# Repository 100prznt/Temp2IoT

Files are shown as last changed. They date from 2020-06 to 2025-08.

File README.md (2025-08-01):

Temp2IoT wiring

# Temp2IoT
Very basic IoT thermometer with REST API and Web-UI. Implemented according to the "KISS" approach - **K**eep **I**t **S**imple and **S**tupid

## Features
* Temperature measurement at one or two measuring points using DS18B20 sensors
* Shows the measured values on integrated web UI
* REST API for integration with master systems (e.g. ioBroker)
* Configuration also via a web UI

## Hardware

### BOM

| Description | Qty. | Price | ASIN (partner-link from amazon.de) |
|---|---|---:|---|
| WeMos D1 mini | 1 | EUR 6,49  | [B01N9RXGHY](https://amzn.to/3clRAiP) |
| DS18B20 waterproof | 1 or 2 | EUR 3,50  | [B01MZG48OE](https://amzn.to/2NQUkvc) |
| Resistor 2K2 (0,6 W) | 1 | EUR 0,99  | [B007R3QXUE](https://amzn.to/3ja1jww) |
|----------------------|--------|-----------|---------------------------------------|
| Total | | EUR 10,98 | |

*quoted prices from 2022/09/08*

Also a USB-micro cable and a USB power supply is required

### Wiring

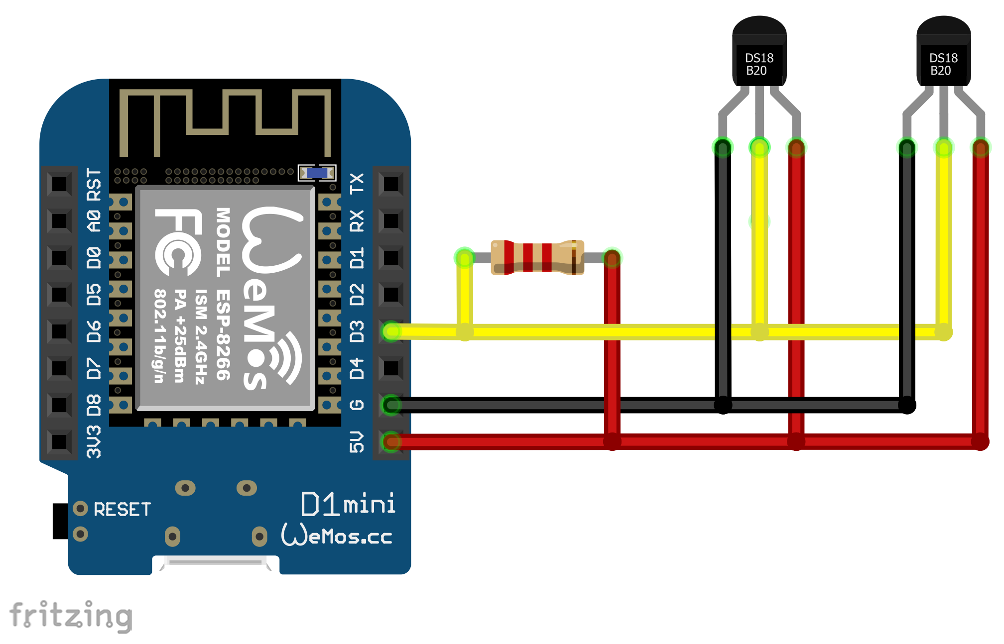
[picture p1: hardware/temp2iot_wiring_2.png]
Temp2IoT wiring


### Power Supply
:warning: Caution Danger to life :warning:

If the thermometer is used to measure water temperatures, it is essential to use an appropriately classified power supply unit. It is important that the power supply is designed as a safety transformer.

A simple USB power supply that meets these requirements can be found here:
* [5V USB-Netzteil mit Sicherheitstransformator | 07-314.0](https://shop.stegertrafo.de/5v-usb-netzteil-mit-sicherheitstransformator-07-314-0.html)

Temp2IoT wiring
Symbol of a short-circuit proof, closed safety transformer 

### Photos

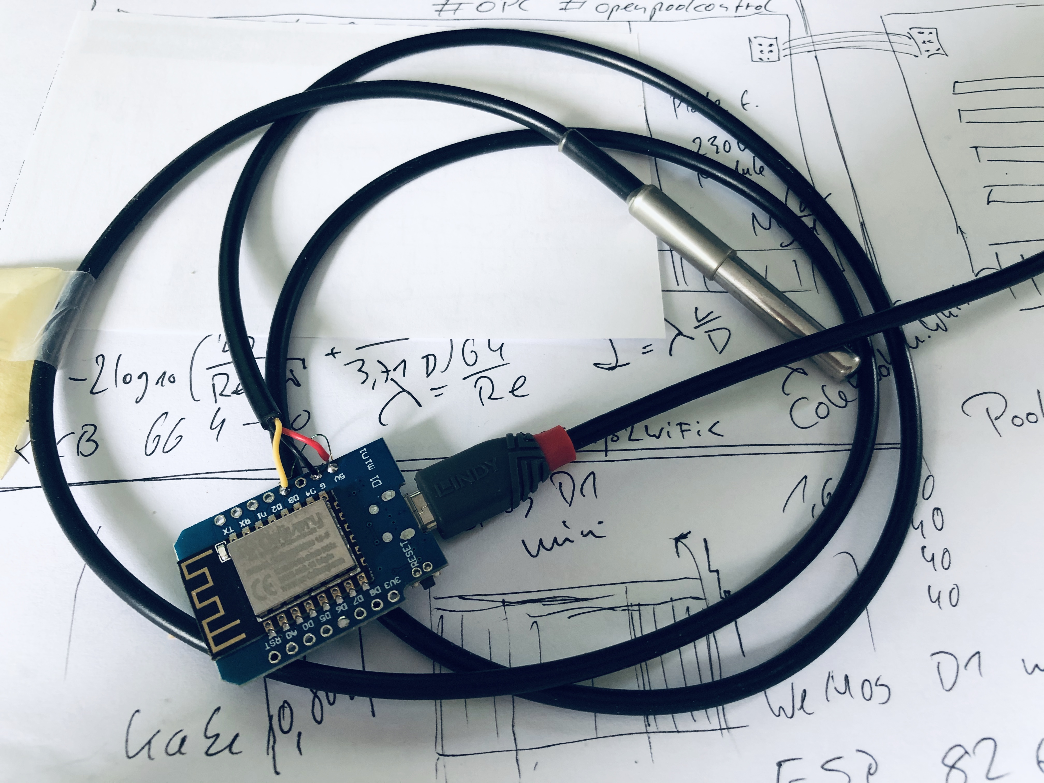
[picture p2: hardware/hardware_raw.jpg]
Temp2IoT minimal build up

Minimal build up with SMD resistor on the back and only one connected DS18B20. 

## Setup

You have two options to upload the software to the WeMos D1 mini.

### ESP8266 Flasher (Windows)

You can download the compiled Flasher Tool from the GitHub Repository
* [nodemcu/nodemcu-flasher](https://github.com/nodemcu/nodemcu-flasher)

1. Clone or download the repository
2. Start the ESP8266Flasher.exe
3. Select the pre-compiled Temp2IoT binary on the config-tab, find at: `src\Temp2IoT\Temp2IoT.ino.d1_mini.bin` (https://github.com/100prznt/Temp2IoT/blob/master/src/Temp2IoT/Temp2IoT.ino.d1_mini.bin)
4. Switch back to the operation-tab and select the right COM-port
5. Press the Flash-Button

## REST API
* URL: `http://<Temp2IoT IP>/api`
* Method: `GET`

```
{
  "systemname": "My Temp2IoT instance",
  "secure_counter": 50,
  "firmware": "2.2.04-b",
  "sensors": [
    {
      "name": "water",
      "value": 23.625,
      "mean-1": {
        "count": 5,
        "value": 23.6,
        "period": 3600
      },
      "mean-24": {
        "count": 5,
        "value": 23.6,
        "period": 86400
      },
      "unit": "Celsius",
      "time": "Fri Jul  9 13:12:36 2021"
    },
    {
      "name": "ambient",
      "value": 23.9375,
      "unit": "Celsius",
      "time": "Fri Jul  9 13:12:37 2021"
    }
  ]
}
```

## Web UI
* URL: `http://<Temp2IoT IP>/`
  <br>
  <br>
  <br>
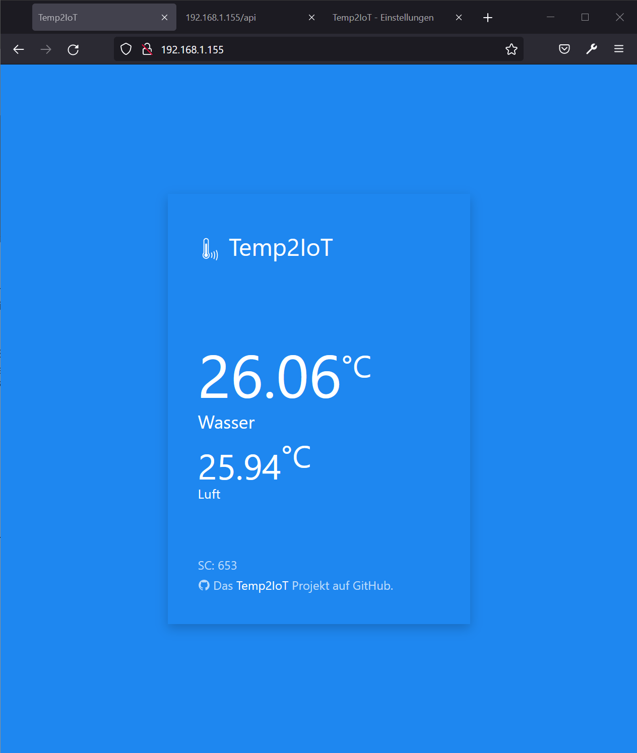
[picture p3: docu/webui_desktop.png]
Web UI on a desktop browser

Web UI on a desktop browser
  <br>
  <br>
  <br>
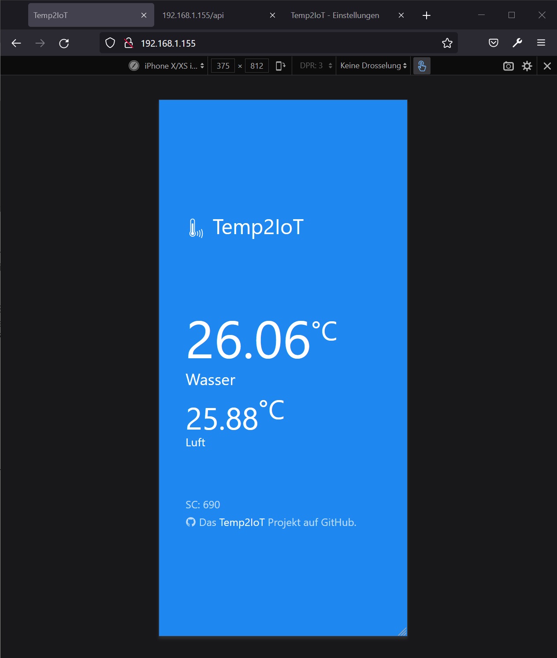
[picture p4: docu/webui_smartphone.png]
Web UI on a smartphone browser

Web UI on a smartphone browser

## System Setup
* URL: `http://<Temp2IoT IP>/setup/`
  <br>
  <br>
  <br>
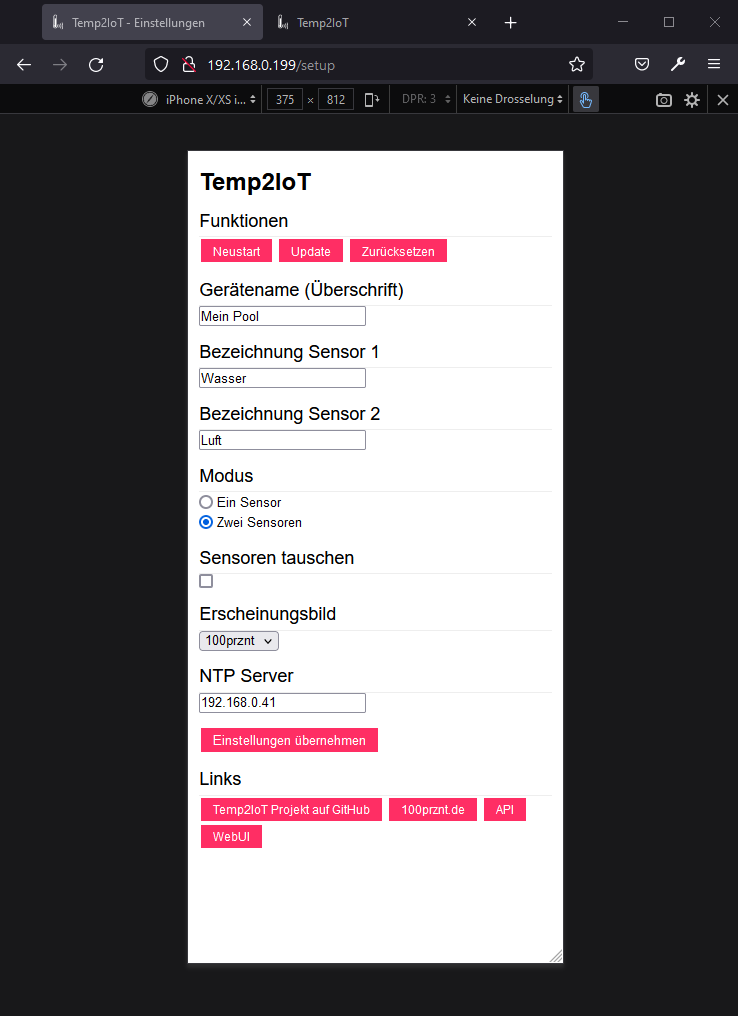
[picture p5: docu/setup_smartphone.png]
Web setup page on a smartphone browser

Setup page on a smartphone browser

## Color Scheme
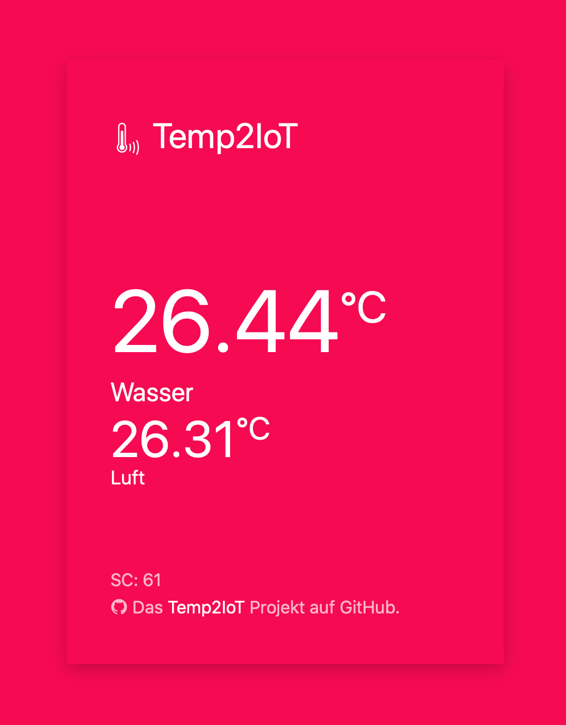
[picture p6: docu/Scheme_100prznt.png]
Temp2IoT Color Scheme 100prznt
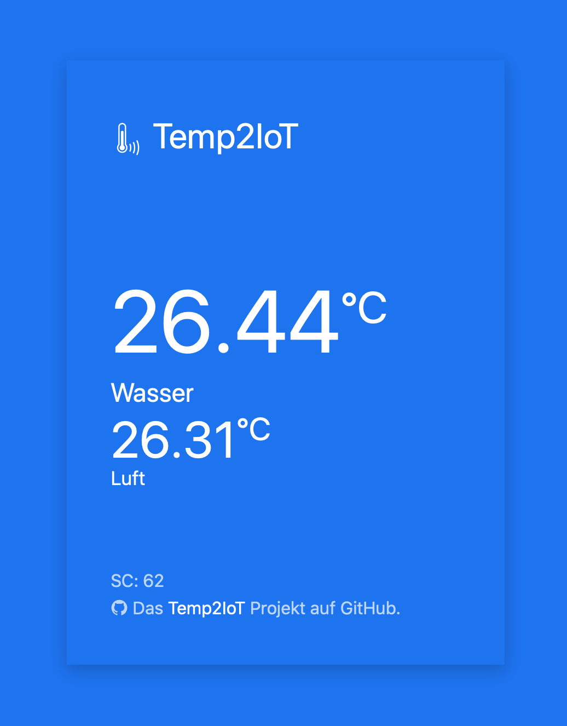
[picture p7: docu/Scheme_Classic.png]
Temp2IoT Color Scheme CLASSIC
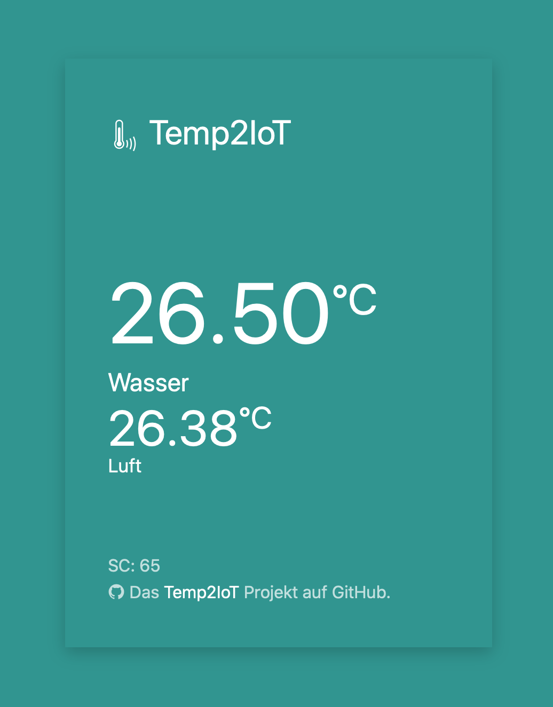
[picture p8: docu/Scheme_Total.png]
Temp2IoT Color Scheme TOTAL
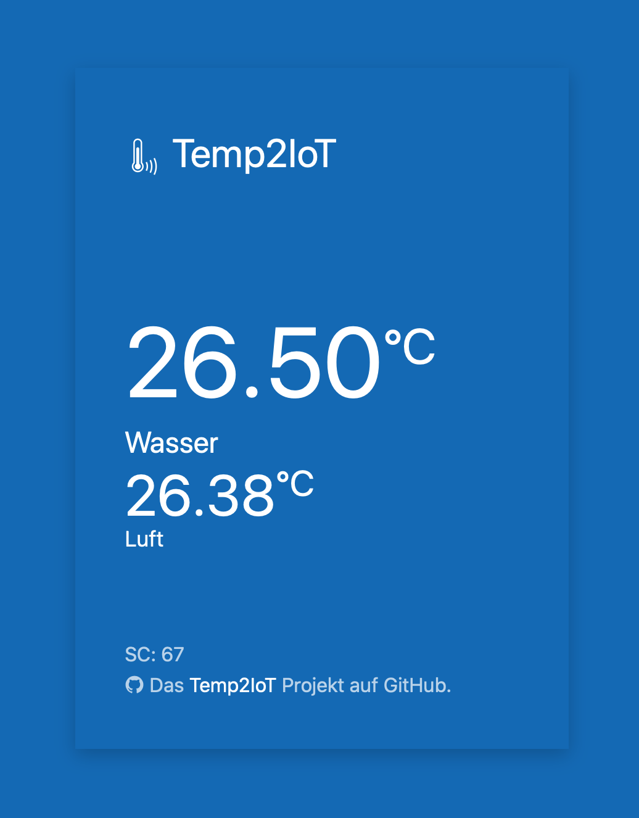
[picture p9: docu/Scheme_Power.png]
Temp2IoT Color Scheme POWER
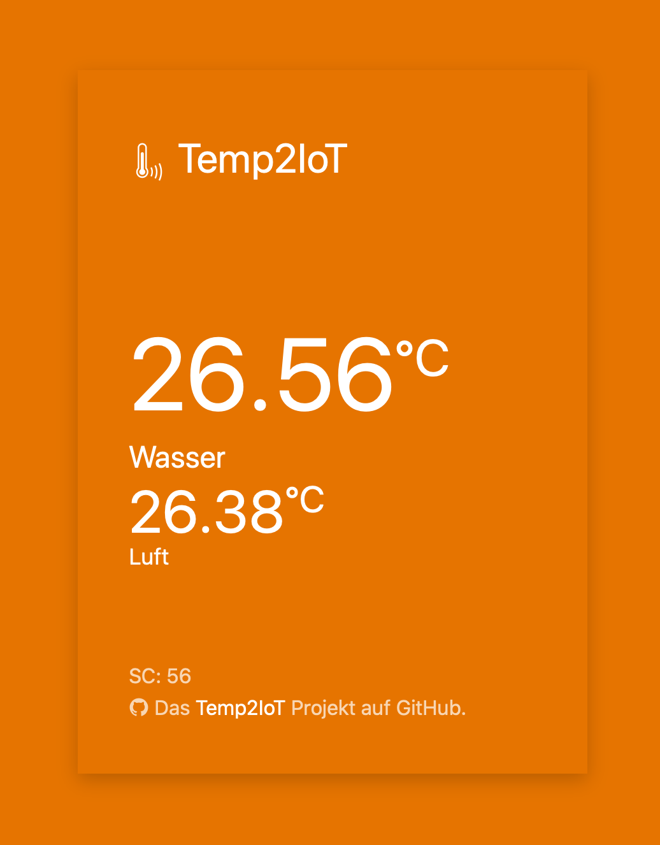
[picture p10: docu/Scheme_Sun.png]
Temp2IoT Color Scheme SUN
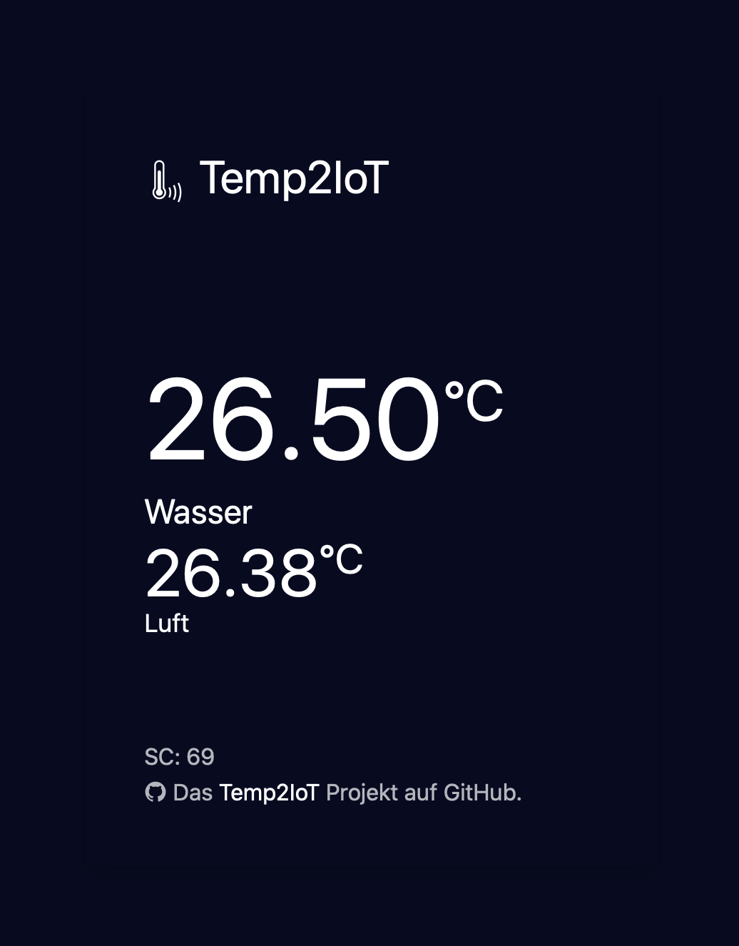
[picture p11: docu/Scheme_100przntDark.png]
Temp2IoT Color Scheme DARK
          

### Colors

| # | scheme | primary color | badge |
|:--|:---|:---|---|
| 1 | 100prznt | `#ff2e64` |  |
| 2 | Classic  | `#1e87f0` |  |
| 3 | Total | `#30a4a1` |  |
| 4 | Power | `#325c84` |  |
| 5 | Sun | `#f08a00` |  |
| 6 | Dark | `#060d2a` |  |

## Debug Output

Feel free to take a look at the serial monitor (115200 baud).

```
21:54:57.656 ->
21:54:57.656 ->        _____               ___ ___    _____       
21:54:57.656 ->       |_   _|__ _ __  _ __|_  )_ _|__|_   _|      
21:54:57.702 ->         | |/ -_) '  \| '_ \/ / | |/ _ \| |        
21:54:57.702 ->         |_|\___|_|_|_| .__/___|___\___/|_|        
21:54:57.702 ->                      |_|                          
21:54:57.702 -> 
21:54:57.702 -> **************************************************
21:54:57.702 ->        a 100prznt.de project by E. Ruemmler       
21:54:57.702 ->                       v2.2.04-b
21:54:57.702 -> 
```

## Enclosure
In the folder [hardware/enclosure](hardware/enclosure) you will find 2 STL files of a suitable enclosure. If the cover is printed upside-down, you can print the first two layers in a different color to make the Temp2IoT icon stand out better.

### Photos

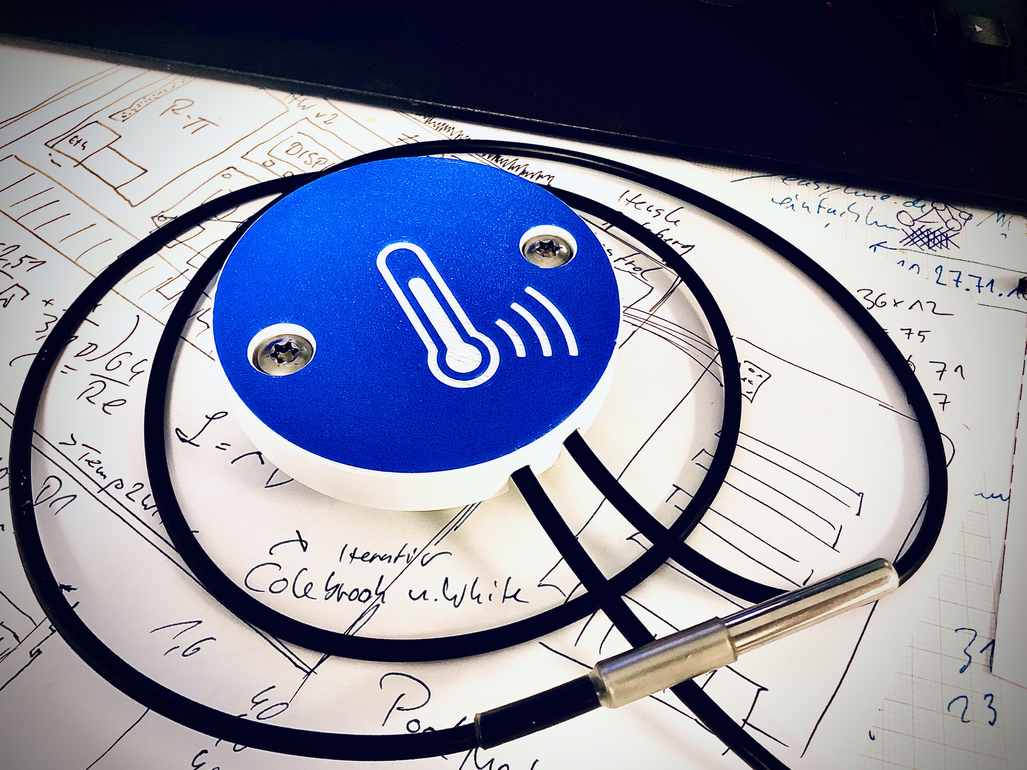
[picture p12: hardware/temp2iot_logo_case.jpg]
3d-printed enclousure with Temp2IoT icon

3d-printed enclousure with Temp2IoT icon
  <br>
  <br>
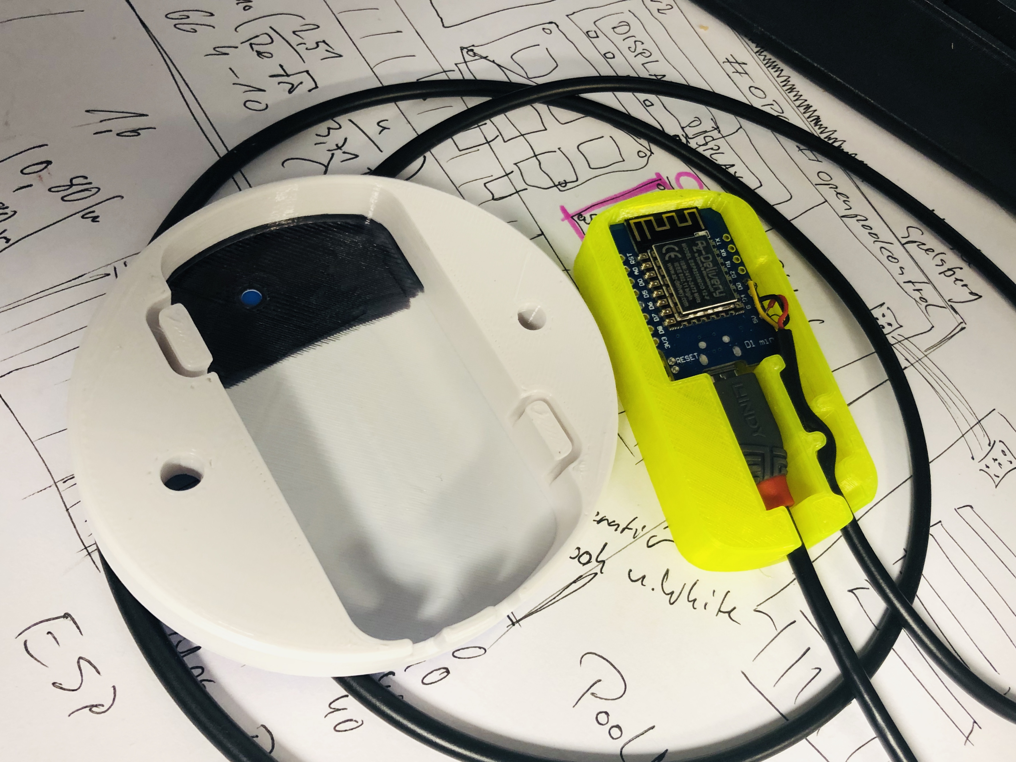
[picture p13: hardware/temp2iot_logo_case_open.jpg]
3d-printed enclousure open

Blackened inside so that the LED produces a focused light spot

## Community
Found this project on the german [Poolpowershop-Forum](https://www.poolpowershop-forum.de/).
* [WiFi Thermometer für 10 Euro selbst gebaut (Web UI, REST API)](https://www.poolpowershop-forum.de/forum/thread/1103493-wifi-thermometer-f%C3%BCr-10-euro-selbst-gebaut-web-ui-rest-api/)

## Credits
This app is made possible by contributions from:
* [Elias Rümmler](http://www.100prznt.de) ([@rmmlr](https://github.com/rmmlr)) - core contributor

### Open Source Project Credits

* [Follower Counter](https://github.com/jegade/followercounter) - The architeture of Temp2IoT based on a awesome code from [@jegade](https://github.com/jegade) used for his followercounter project.
* Used Arduino libraries are described in the code.

## License
The Temp2IoT project is licensed under [MIT](http://www.opensource.org/licenses/mit-license.php "Read more about the MIT license form"). Refer to [LICENSE.txt](https://github.com/100prznt/Temp2IoT/blob/master/LICENSE.txt) for more information.

## Contributions
Contributions are welcome. Fork this repository and send a pull request if you have something useful to add.

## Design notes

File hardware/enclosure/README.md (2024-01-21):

# Temp2IoT Enclosure

The enclosure is optimized for the use of a LINDY *Anthra Line Anthrazit* USB cable.

Partner-link from amazon.de
* [LINDY 36734 3m USB 2.0 Typ A an Micro-B Kabel](https://amzn.to/2YbEmhI)

## STLs

You can find the STL files for the case on Printables.com
* [WeMos D1 mini Enclosure](https://www.printables.com/de/model/44083-wemos-d1-mini-enclosure)

## Assembly

If the cover is printed in a bright color, it can be blackened from the inside to prevent the LED from causing unpleasant stray light.

Printed enclosure parts

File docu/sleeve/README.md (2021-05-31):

Temp2IoT wiring

# Temp2IoT
Very basic IoT thermometer with REST API and Web-UI. Implemented according to the "KISS" approach - **K**eep **I**t **S**imple and **S**tupid

* Go to Project [README.md](https://github.com/100prznt/Temp2IoT)

## Tauchhülse
Möchte man die Wassertemperatur im geschlossenen Kreislauf erfassen bietet sich der Einsatz einer Tauchhülse an. Eine solche Tauchhülse kann zum Beispiel in ein T-Stück mit reduzierten Abgang eingeschraubt werden.

Im Vergleich zu einen außenliegenden Anlegefühler erreicht man mit der Tauchhülse eine wesentlich bessere Dynamik. Die dünnwandige Edelstahl-Hülse leitet wäre einfach besser als ein dickwandiges PVC Rohr.

## BOM

| Description | Qty. | Price | ASIN (partner-link from amazon.de) |
|:---|:-----|---:|:---|
| Tauchhülse 1/2" 50 mm | 1 | EUR 10,99 | [ B07DXFWV6B](https://amzn.to/3eissJy) |

*quoted prices from 2021/04/19*

## Photos

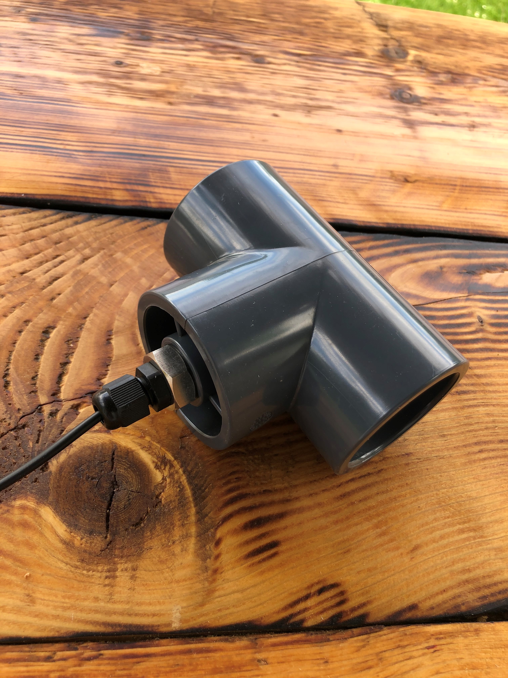
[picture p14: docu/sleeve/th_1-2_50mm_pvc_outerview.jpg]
Im T-Stück eingesetzte Tauchhülse mit 1/2" Gewinde

Im T-Stück eingesetzte Tauchhülse mit 1/2" Gewinde
  <br>
  <br>
  <br>
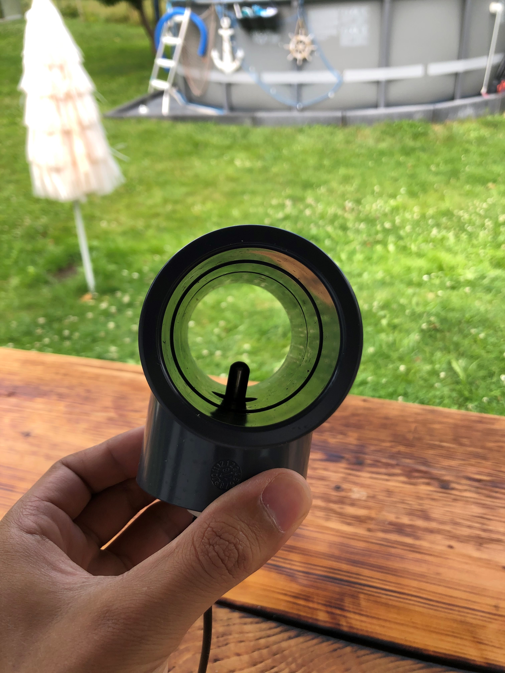
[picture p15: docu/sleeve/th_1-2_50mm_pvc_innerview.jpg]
Mit 50 mm Länge ragt die Hülse minimal in den Hautstrom

Mit 50 mm Länge ragt die Hülse minimal in den Hautstrom. Tieferes Eintauchen erhöht das Risiko das sich Haare festsetzen.

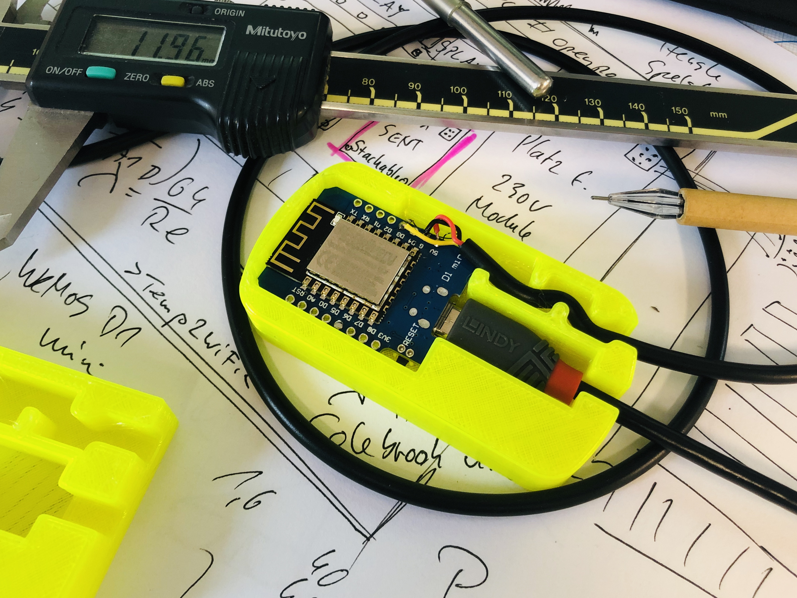
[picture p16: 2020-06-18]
hardware/first_case.jpg

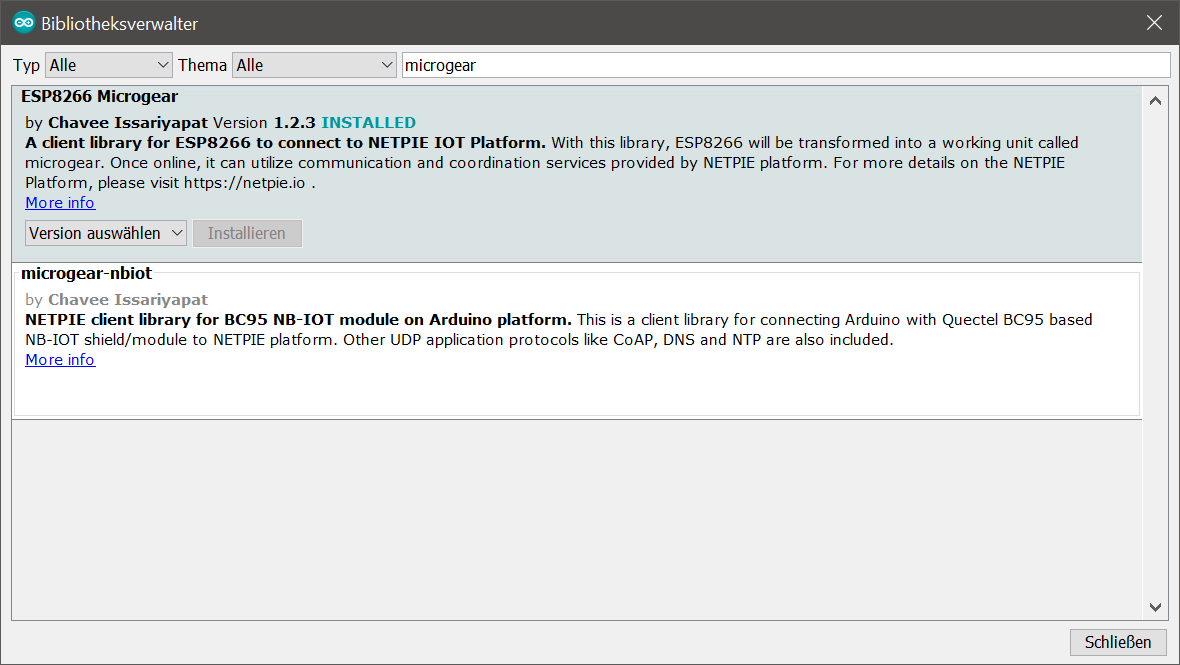
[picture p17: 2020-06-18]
docu/ide_microgear_lib.png

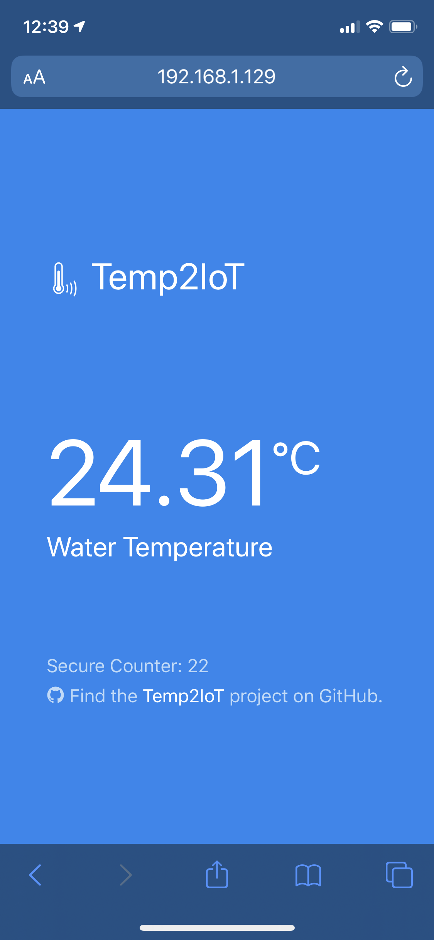
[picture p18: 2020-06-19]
docu/webui_smartphone_real.png

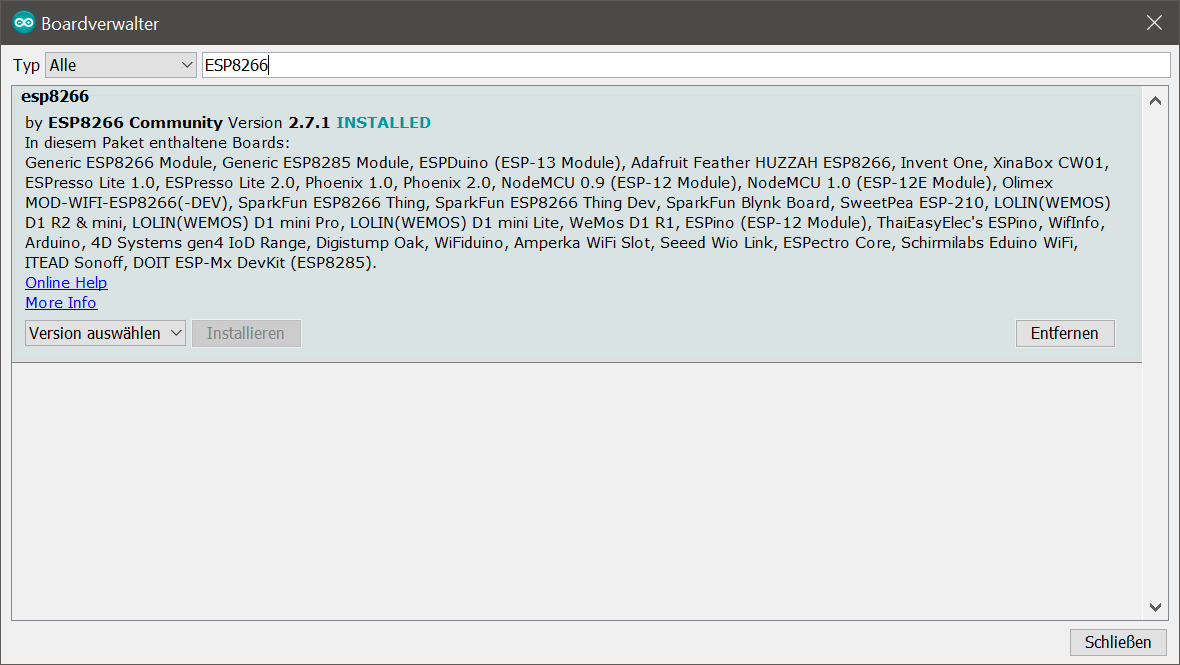
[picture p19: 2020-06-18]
docu/ide_boards.png

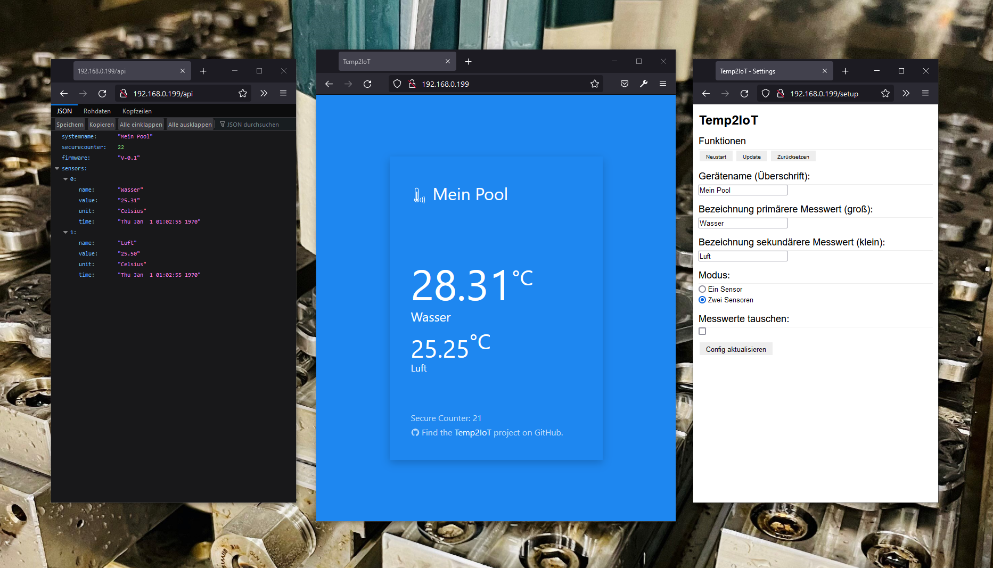
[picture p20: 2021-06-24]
docu/dev_view_v2.png

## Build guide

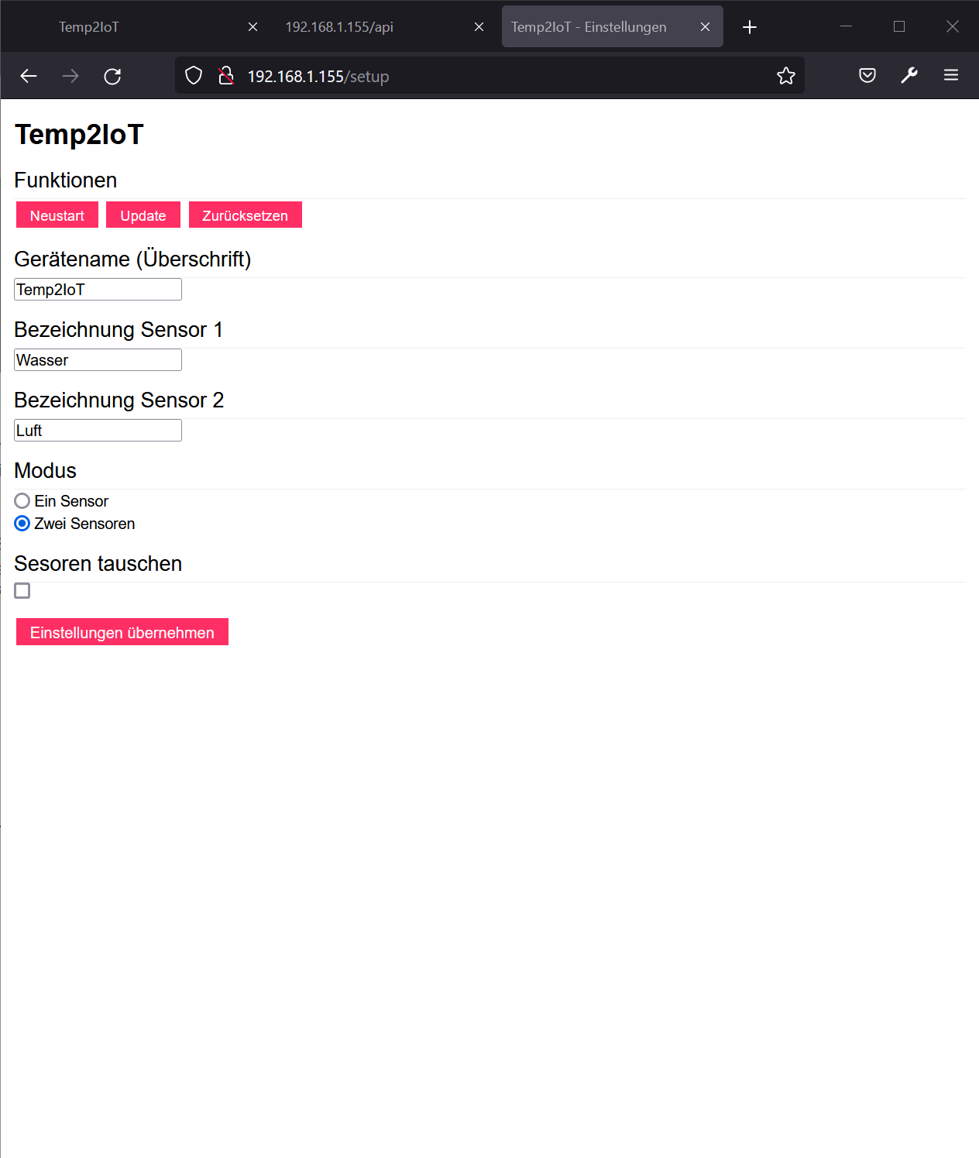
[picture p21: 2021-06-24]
docu/setup_desktop.png

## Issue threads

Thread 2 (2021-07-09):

1-Wire reading failure

100prznt, 2021-07-09:
Check the temperature values for plausibility. Detect and mark faulty values -> return NaN.

100prznt, 2021-07-15:
Implemented in 5e270a9

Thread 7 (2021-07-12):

Unhandled Exception and HttpUpdate fails

100prznt, 2021-07-12:
ESP restart after unhandled exception (mem alloc) and after try to start HttpUpdate.

WiFiManager also don't work... 👎🏻

100prznt, 2021-07-12:
Problem eingegrenzt. Wird durch cppQueue ausgelöst.

Closed 2021-07-14.

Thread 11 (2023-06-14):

4 Sensors

uncle03, 2023-06-14:
Hi,

we have the choice between 1 and 2 sensors. ist it also possible to get 4 sensors ?

So I see: Heatpump in/Heatpump out, bottom pool Temperature and air temperature.

100prznt, 2023-06-14:
The structures for storing and processing sensor data are currently fixed for two sensors. If more sensors should be processed, it's better to change the software architecture so that the processing takes place in dynamic fields (arrays).

Best regards Elias

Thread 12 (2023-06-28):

Keine WLAN Verbindung

ZeroQool007, 2023-06-28:
Hallo, irgendwie baut das WEMOS keine WLAN Verbindung zu meinem Netz auf. Die Zugangsdaten sind korrekt (GroßKleinschreibung und Sonderzeichen).

Im Handy sehe ich der irgendwann den HotSpot aufmacht u dann connecte ich mich mit der 192.168.4.1 Die Temperaturwerte sind auch wild.

Hast du einen Tip? Danke

100prznt, 2023-06-30:
Verbinde den D1-mini mal mit einem PC und verbinde ein Terminal auf den COM-Port. Nach einem Reset (vom D1-mini) werden einige Meldungen ausgegeben, dieses könntest du mal hier einstellen.

Siehe auch: https://github.com/100prznt/Temp2IoT#debug-output

Beste Grüße Elias

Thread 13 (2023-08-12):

Ansicht auf dem Smartphone

Hilti23, 2023-08-12:
Hi,
ich kann die Seite zwar auf dem PC anschauen, aber auf dem Android Smartphone läd er die Seite nicht und zeigt den Fehler err_address _unreachable.
Beides der Chrome.
Dieses Verhalten könnte ich sonst noch nicht beobachten.

Für alle bei denen der Pin D3 nicht funktioniert: Bei mir geht's nur auf D1.

Und noch eine Frage: kann ich die Kabel des Temperatur Sensoren um ca. 1 M verlängern und er zeigt noch einigermaßen die korrekte Temperatur?
Danke✌🏻
Jürgen

100prznt, 2023-08-15:
Hallo Jürgen,

die Fehlermeldung hört sich nach einen DNS Problem auf dem Endgerät an. Versuche mal bei der Adresseingabe explizit "http://<IP vom Temp2IoT>".

Die Pins am ESP8266 sind mehrfach belegt, da kan es schon sein, dass man unter bestimmten Bedingungen mit einem anderen Pin ein anderes Verhalten erreicht. Werde diese Info auf jeden Fall im Hinterkopf behalten, vielen Dank.

1 m Verlängerung ist unkritisch und hat beim DS18B20 keinen Einfluss auf die Genauigkeit.

Beste Grüße Elias

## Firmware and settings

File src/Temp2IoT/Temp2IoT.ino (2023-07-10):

/**
 * Temp2IoT
 * Very basic IoT thermometer with REST API and web UI,
 * based on ESP8266 hardware (WeMos D1 mini) 
 *
 * a 100prznt.de project by E. Ruemmler
 *
 *
 * C++11
 *
 * Copyright (C) 2023  Elias Ruemmler
 *
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
 * @package		Temp2IoT
 * @author		Elias Ruemmler <e.ruemmler@rc-art.de>
 * @copyright	2023 RC-Art Solutions
 * @version		2.3
 * @link		  https://github.com/100prznt/Temp2IoT
 * @since		  2020-06-17
 *
 *
 * The architecture of this project is based on the code of @jegade his followercounter.
 * https://github.com/jegade/followercounter
 */


#include <FS.h>						          // this needs to be first, or it all crashes and burns...

#include "Arduino.h"
#include <ESP8266WiFi.h>
//#include "JsonStreamingParser.h"	// Json Streaming Parser 		https://github.com/squix78/json-streaming-parser

#include <ESP8266HTTPClient.h>		  // Web Download
#include <ESP8266httpUpdate.h>		  // Web Updater

#include <ArduinoJson.h>			      // ArduinoJson 				    	https://github.com/bblanchon/ArduinoJson

#include <DNSServer.h>				      // Local DNS Server used for redirecting all requests to the configuration portal
#include <ESP8266WebServer.h>		    // Local WebServer used to serve the configuration portal
#include <WiFiManager.h>			      // WifiManager 				    	https://github.com/tzapu/WiFiManager


#include <NTPClient.h>				      // Connect to a NTP Server	https://github.com/arduino-libraries/NTPClient
#include <time.h>

#include <Arduino.h>

#include <ESPStringTemplate.h>		  // ESPStringTemplate		  	https://github.com/DaleGia/ESPStringTemplate

#include <DallasTemperature.h>		  // Maxim Temperature ICs		https://github.com/milesburton/Arduino-Temperature-Control-Library
#include <OneWire.h>				        // 1-Wire library			    	https://www.pjrc.com/teensy/td_libs_OneWire.html
#include <stdio.h>


#include "index.h"
#include "config.h"
#include "favicon.h"


#define VERSION "2.3.06-b"
#define USE_SERIAL Serial
#define ONE_WIRE_BUS D3


WiFiClientSecure client;
ESP8266WebServer server(80);


OneWire oneWire(ONE_WIRE_BUS);
DallasTemperature DS18B20(&oneWire);
char Temperature1Str[6] = "NaN";
char Temperature2Str[6] = "NaN";
float MeasValue1;
float MeasValue2;

unsigned int SecureCounter;

char time_value[20];

//define your default values here, if there are different values in config.json, they are overwritten.
char systemName[20] = "Temp2IoT";
char temp1Name[20] = "Water Temperature";
char temp2Name[20] = "Ambient Temperature";
int colorScheme = 1;
int sensorCnt = 2;
bool toggleSensors;
char ntpServer[20] = "time.nist.gov";
//parameters for calibration polynom (2. order)
//squareValue * x^2 + gainValue * x + offsetValue
float offsetValue1 = 0;
float offsetValue2 = 0;
float gainValue1 = 1;
float gainValue2 = 1;
float squareValue1 = 0;
float squareValue2 = 0;

//init up
char measTime[26] = "Thu Jan  1 00:00:00 1970";
char primaryColor[8] = "#ff2e64"; //"#1e87f0"
char htmlBuffer[8000];


//data storage for tend analysis
#define MEMORY_DEPTH 1440 //count of measvalues which are held in the ring buffer
#define MEMORY_VALUES_PER_HOUR 60 //value must be divisor of 720

float MeasValues[MEMORY_DEPTH];
int MeasValues_Index = 0;
bool MeasValues_IsFull = false;

float MeasValueMean;
int cnt_Readings = 720 / MEMORY_VALUES_PER_HOUR;
float MeasValueInterval = 3600.0 / MEMORY_VALUES_PER_HOUR;

//=======================================================================


//flag for saving data
bool shouldSaveConfig = true;

//callback notifying us of the need to save config
void saveConfigCallback()
{
	USE_SERIAL.println("Should save config");
	shouldSaveConfig = true;
}

void handleRoot()
{
	ESPStringTemplate webpage(htmlBuffer, sizeof(htmlBuffer));

	TokenStringPair pair_Style[1];
	pair_Style[0].setPair("%COLORPRIM%", primaryColor);

	TokenStringPair pair_SystemName[1];
	pair_SystemName[0].setPair("%NAME%", systemName);

	TokenStringPair pair_Data[4];

	if (toggleSensors)
	{
		pair_Data[0].setPair("%T1%", Temperature2Str);
		pair_Data[1].setPair("%N1%", temp2Name);
		pair_Data[2].setPair("%T2%", Temperature1Str);
		pair_Data[3].setPair("%N2%", temp1Name);
	}
	else
	{
		pair_Data[0].setPair("%T1%", Temperature1Str);
		pair_Data[1].setPair("%N1%", temp1Name);
		pair_Data[2].setPair("%T2%", Temperature2Str);
		pair_Data[3].setPair("%N2%", temp2Name);
	}

	TokenStringPair pair_SecureCounter[1];
	char secureCounterStr[20];
	itoa(SecureCounter, secureCounterStr, 10);
	pair_SecureCounter[0].setPair("%SC%", secureCounterStr);

	webpage.add_P(_PAGE_WEBUI_HEAD, pair_Style, 1);

	webpage.add_P(_PAGE_WEBUI_CARDHEAD, pair_SystemName, 1);
	
	if (sensorCnt == 2)
		webpage.add_P(_PAGE_WEBUI_CARDBODY, pair_Data, 4);
	else
		webpage.add_P(_PAGE_WEBUI_CARDBODYSINGLE, pair_Data, 2);

	webpage.add_P(_PAGE_WEBUI_CARDFOOTER, pair_SecureCounter, 1);
	
	if (sensorCnt == 2)
	{
		if (toggleSensors)
			webpage.add_P(_PAGE_WEBUI_FOOTER_SCRIPT2_TOGGLED);
		else
			webpage.add_P(_PAGE_WEBUI_FOOTER_SCRIPT2);
	}
	else
		webpage.add_P(_PAGE_WEBUI_FOOTER_SCRIPT1);

	server.send(200, "text/html", htmlBuffer);
}

void handleFaviconSvg()
{
	server.send(200, "image/svg+xml", _FAVICON_SVG_WHITE);
}

void handleApi()
{
	char JSONmessageBuffer[1024];
	DynamicJsonDocument doc(1024);

	doc["systemname"] = systemName;
	doc["secure_counter"] = SecureCounter;
	doc["firmware"] = VERSION;
	doc["sensors"][0] = getData(1);
	if (sensorCnt == 2)
		doc["sensors"][1] = getData(2);

	serializeJsonPretty(doc, JSONmessageBuffer);

	server.send(200, "application/json", JSONmessageBuffer);
}

DynamicJsonDocument getData(int idx)
{
	DynamicJsonDocument doc(1024);

	switch (idx)
	{
		case 1:
		{
			doc["name"] = temp1Name;
			if (MeasValue1 == 999.9)
				doc["value"] = "NaN";
			else
				doc["value"] = MeasValue1;
			if (!toggleSensors)
			{
				doc["mean-1"] = getData_MeanValue(1);
				doc["mean-24"] = getData_MeanValue(24);
			}
		}
		break;
		case 2:
		{
			doc["name"] = temp2Name;
			if (MeasValue2 == 999.9)
				doc["value"] = "NaN";
			else
				doc["value"] = MeasValue2;
			if (toggleSensors)
			{
				doc["mean-1"] = getData_MeanValue(1);
				doc["mean-24"] = getData_MeanValue(24);
			}
		}
		break;
		default:
		break;
	}

	doc["unit"] = "Celsius";
	doc["time"] = measTime;

	return doc;
}

DynamicJsonDocument getData_MeanValue(int period)
{
	DynamicJsonDocument doc(1024);
	int cnt_MeasValues_InUse = 0;
	
	int periodSec = period * 3600; //to [sec]
	//periodSec = 300; //5 min
	
	int offset = periodSec / MeasValueInterval; //round?
	
	USE_SERIAL.print("offset = ");
	USE_SERIAL.println(offset);

	if (offset > MEMORY_DEPTH || (!MeasValues_IsFull && MeasValues_Index < offset))
	{
		doc["value"] = "NaN";
	}
	else
	{
		float sum = 0;

		if (MeasValues_Index >= offset) //no overflow
		{
			//Meanvalue calculation
			for (int i = MeasValues_Index - offset; i < MeasValues_Index; i++)
			{
				sum += MeasValues[i];
				cnt_MeasValues_InUse++;
			}
		}
		else //with overflow
		{
			for (int i = 0; i < MeasValues_Index; i++)
			{
				sum += MeasValues[i];
				cnt_MeasValues_InUse++;
			}

			int firstIdx = MEMORY_DEPTH - (offset - MeasValues_Index);
			for (int i = firstIdx; i < MEMORY_DEPTH; i++)
			{
				sum += MeasValues[i];
				cnt_MeasValues_InUse++;
			}
		}

		doc["value"] = sum / cnt_MeasValues_InUse;
	}

	doc["count"] = cnt_MeasValues_InUse;
	doc["period"] = periodSec;

	return doc;
}

void handleConfig()
{
	ESPStringTemplate webpage(htmlBuffer, sizeof(htmlBuffer));

	TokenStringPair pair_Style[1];
	pair_Style[0].setPair("%COLORPRIM%", primaryColor);

	TokenStringPair pair[5];
	pair[0].setPair("%SYSNAME%", systemName);
	pair[1].setPair("%VERSION%", VERSION);
	pair[2].setPair("%SENSOR1NAME%", temp1Name);
	pair[3].setPair("%SENSOR2NAME%", temp2Name);
	pair[4].setPair("%NTPSERVER%", ntpServer);

	webpage.add_P(_PAGE_HEAD, pair_Style, 1);
	webpage.add_P(_PAGE_START), pair, 2;

	webpage.add_P(_PAGE_ACTIONS);

	webpage.add_P(_PAGE_CONFIG_SYSNAME, pair, 1);
	webpage.add_P(_PAGE_CONFIG_SENSOR1NAME, pair, 3);
	webpage.add_P(_PAGE_CONFIG_SENSOR2NAME, pair, 4);
	

	switch (sensorCnt)
	{
		case 1:
			webpage.add_P(_PAGE_CONFIG_SENSORCNT1);
			break;
		case 2:
			webpage.add_P(_PAGE_CONFIG_SENSORCNT2);
			break;
		default:
			webpage.add_P(_PAGE_CONFIG_SENSORCNT1);
			break;
	}

	if (toggleSensors)
		webpage.add_P(_PAGE_CONFIG_SENSORTOOGLETRUE);
	else
		webpage.add_P(_PAGE_CONFIG_SENSORTOOGLEFALSE);

	switch (colorScheme)
	{
		case (2):
			webpage.add_P(_PAGE_CONFIG_COLORSCHEME_2);	
			break;
		case (3):
			webpage.add_P(_PAGE_CONFIG_COLORSCHEME_3);	
			break;
		case (4):
			webpage.add_P(_PAGE_CONFIG_COLORSCHEME_4);	
			break;
		case (5):
			webpage.add_P(_PAGE_CONFIG_COLORSCHEME_5);	
			break;
		case (6):
			webpage.add_P(_PAGE_CONFIG_COLORSCHEME_6);	
			break;
		default: //1 -> 100prznt
			webpage.add_P(_PAGE_CONFIG_COLORSCHEME_1);	
			break;
	}

	webpage.add_P(_PAGE_CONFIG_NTP, pair, 5);

	webpage.add_P(_PAGE_FOOTER);

	server.send(200, "text/html", htmlBuffer);
}

void redirectBack()
{
	server.sendHeader("Location", String("/"), true);
	server.send ( 302, "text/plain", "");
}

void getConfig()
{
	String systemNameString = server.arg("systemName");
	systemNameString.toCharArray(systemName,20);
	String temp1NameString = server.arg("temp1Name");
	temp1NameString.toCharArray(temp1Name,20);
	String temp2NameString = server.arg("temp2Name");
	temp2NameString.toCharArray(temp2Name,20);

	String toggleSensorsString = server.arg("toggleSensors");
	bool buffer = false;
	if (toggleSensorsString == "on")
		buffer = true;

	if (buffer != toggleSensors)
	{
		USE_SERIAL.println("# Buffer.Clear");
		MeasValues_IsFull = false;
		MeasValues_Index = 0;
		toggleSensors = buffer;
	}

	//sensorCnt
	String sensorCntString = server.arg("sensorCnt");
	sensorCnt = sensorCntString.toInt();

	//colorScheme
	String colorSchemeString = server.arg("colorScheme");
	colorScheme = colorSchemeString.toInt();

	switch (colorScheme)
	{
		case 2: //Classic
			String("#1e87f0").toCharArray(primaryColor, 8);		
			break;
		case 3: //Total
			String("#30a4a1").toCharArray(primaryColor, 8);		
			break;
		case 4: //Power
			String("#325c84").toCharArray(primaryColor, 8);	
			break;
		case 5: //Sun
			String("#f08a00").toCharArray(primaryColor, 8);	
			break;
		case 6: //100prznt secondary
			String("#060d2a").toCharArray(primaryColor, 8);	
			break;
		default: //1 -> 100prznt
			String("#ff2e64").toCharArray(primaryColor, 8);	
			break;
	}

	String ntpServerString = server.arg("ntpServer");
	ntpServerString.toCharArray(ntpServer,20);

	saveConfig();
	redirectBack();
}

void getReset()
{
	redirectBack();
	restartX();
}

void getUpdate()
{
	redirectBack();
	updateFirmware();
}

void getFormat()
{
	redirectBack();
	infoReset();
}

float checkTemperature(float value)
{
	//HACK: use 999.9 as indicator for NaN

	if (value == -127.0)
		return 999.9;
	else if (value == 0.0)
		return 999.9;
	else if (value == 85.0)
		return 999.9;
	else if (value == 127.0)
		return 999.9;
	else if (value == 127.94)
		return 999.9;
	else
		return value;
}

void readTemperature() {
	USE_SERIAL.print("Start new reading on 1-Wire bus, SC = ");
	USE_SERIAL.println(SecureCounter);

	digitalWrite(LED_BUILTIN, LOW);  //turn the LED on

	time_t now = time(nullptr);
	String time = String(ctime(&now));
	time.toCharArray(measTime, 25);


	String nanStr = "NaN";
	bool readingError = false;
	int cnt = 3; //retry counter

	do
	{
		DS18B20.requestTemperatures(); 
		MeasValue1 = checkTemperature(DS18B20.getTempCByIndex(0));
		if (MeasValue1 == 999.9)
		{
			readingError = true;
			nanStr.toCharArray(Temperature1Str, 6);
		}
		else
		{
			MeasValue1 = squareValue1 * pow(MeasValue1, 2) + gainValue1 * MeasValue1 + offsetValue1;
			dtostrf(MeasValue1, 5, 2, Temperature1Str);
		}

		if (sensorCnt > 1)
		{
			MeasValue2 = checkTemperature(DS18B20.getTempCByIndex(1));
			if (MeasValue2 == 999.9)
			{
				readingError = true;
				nanStr.toCharArray(Temperature2Str, 6);
			}
			else
			{
				MeasValue2 = squareValue2 * pow(MeasValue2, 2) + gainValue2 * MeasValue2 + offsetValue2;
				dtostrf(MeasValue2, 5, 2, Temperature2Str);
			}
		}

		if (!readingError)
			break;
		
		cnt--;
		delay(100);
	} while (cnt > 0);


	//fill measvalue buffer
	cnt_Readings++;
	if (cnt_Readings >= 720 / MEMORY_VALUES_PER_HOUR)
	{
		USE_SERIAL.println("# Store received measvalue in ring buffer");
		
		if (MeasValues_Index >= MEMORY_DEPTH)
		{
			MeasValues_IsFull = true;
			MeasValues_Index = 0;
		}

		if (!toggleSensors)
		{
			if (MeasValue1 == 999.9)
			{
				USE_SERIAL.println("# Invalid temperature reading, ring buffer has been reset!");
				MeasValues_IsFull = false;
				MeasValues_Index = -1;
			}
			else
				MeasValues[MeasValues_Index] = MeasValue1;
		}
		else
		{
			if (MeasValue2 == 999.9)
			{
				USE_SERIAL.println("# Invalid temperature reading, ring buffer has been reset!");
				MeasValues_IsFull = false;
				MeasValues_Index = -1;
			}
			else
				MeasValues[MeasValues_Index] = MeasValue2;
		}

		MeasValues_Index++;
		cnt_Readings = 0;

		USE_SERIAL.print("# Buffer.IsFull = ");
		USE_SERIAL.println(MeasValues_IsFull);
		USE_SERIAL.print("# Buffer.Index = ");
		USE_SERIAL.println(MeasValues_Index);
	}

	SecureCounter++;
	digitalWrite(LED_BUILTIN, HIGH);  //turn the LED off
}

void setup()
{
	//serial debugging
	USE_SERIAL.begin(115200);
	USE_SERIAL.setDebugOutput(true);
	delay(500);

	//print out some crazy startup logo ;)
	USE_SERIAL.println();
	USE_SERIAL.println(R"=====(       _____               ___ ___    _____        )=====");
	USE_SERIAL.println(R"=====(      |_   _|__ _ __  _ __|_  )_ _|__|_   _|       )=====");
	USE_SERIAL.println(R"=====(        | |/ -_) '  \| '_ \/ / | |/ _ \| |         )=====");
	USE_SERIAL.println(R"=====(        |_|\___|_|_|_| .__/___|___\___/|_|         )=====");
	USE_SERIAL.println(R"=====(                     |_|                           )=====");
	USE_SERIAL.println();
	USE_SERIAL.println(R"=====(***************************************************)=====");
	USE_SERIAL.println(R"=====(       a 100prznt.de project by E. Ruemmler        )=====");
	
	USE_SERIAL.print(R"=====(                      v)=====");
	USE_SERIAL.println(VERSION);
	USE_SERIAL.println();
	
	USE_SERIAL.println("Setting up...");

	pinMode(LED_BUILTIN, OUTPUT);	 //initialize the LED_BUILTIN pin as an output
	digitalWrite(LED_BUILTIN, LOW);   //turn the LED on

	client.setInsecure();

	//const uint8_t fingerprint[20] = {0x90, 0x7F, 0x62, 0x4B, 0x5B, 0x7B, 0x70, 0xF6, 0x8A, 0xCE, 0x56, 0x1B, 0xAE, 0x90, 0x0D, 0x49, 0xE4, 0xA5, 0x84, 0x99};
	//client.setFingerprint(fingerprint);



	if (SPIFFS.begin())
	{
		if (SPIFFS.exists("/config.json"))
		{
		//file exists, reading and loading

			File configFile = SPIFFS.open("/config.json", "r");
			if (configFile)
			{
				USE_SERIAL.println("opened config file");
				size_t size = configFile.size();
				//allocate a buffer to store contents of the file.
				std::unique_ptr<char[]> buf(new char[size]);

				configFile.readBytes(buf.get(), size);
				DynamicJsonDocument json(1024);
				deserializeJson(json, buf.get());
				serializeJson(json,Serial);

				JsonVariant jsonSystemName = json["systemName"];
				if (!jsonSystemName.isNull())
					strcpy(systemName, json["systemName"]);

				JsonVariant jsonTemp1Name = json["temp1Name"];
				if (!jsonTemp1Name.isNull())
					strcpy(temp1Name, json["temp1Name"]);

				JsonVariant jsonTemp2Name = json["temp2Name"];
				if (!jsonTemp2Name.isNull())
					strcpy(temp2Name, json["temp2Name"]);

				JsonVariant jsonSensorCnt = json["sensorCnt"];
				if (!jsonSensorCnt.isNull())
					sensorCnt = jsonSensorCnt.as<int>();

				JsonVariant jsonToggleTemps = json["toggleSensors"];
				if (!jsonToggleTemps.isNull())
					toggleSensors = jsonToggleTemps.as<bool>();

				JsonVariant jsonPrimaryColor = json["primaryColor"];
				if (!jsonPrimaryColor.isNull())
					strcpy(primaryColor, json["primaryColor"]);

				JsonVariant jsonNtpServer = json["ntpServer"];
				if (!jsonNtpServer.isNull())
					strcpy(ntpServer, json["ntpServer"]);

				USE_SERIAL.println();
				USE_SERIAL.print("primaryColor: ");
				USE_SERIAL.println(primaryColor);

				if (strcmp(primaryColor, "#1e87f0") == 0)
					colorScheme = 2;
				else if (strcmp(primaryColor, "#30a4a1") == 0)
					colorScheme = 3;
				else if (strcmp(primaryColor, "#325c84") == 0)
					colorScheme = 4;
				else if (strcmp(primaryColor, "#f08a00") == 0)
					colorScheme = 5;
				else if (strcmp(primaryColor, "#060d2a") == 0)
					colorScheme = 6;
				else
					colorScheme = 1;

				USE_SERIAL.print("colorScheme: ");
				USE_SERIAL.println(colorScheme);
			}
			else
				USE_SERIAL.println("failed to open /config.json");
		}
		else
			USE_SERIAL.println("/config.json not found");
	}
	else
		USE_SERIAL.println("failed to mount FS");
	//end read

	WiFiManager wifiManager;
	wifiManager.setCustomHeadElement("<style>button,input[type='button'],input[type='submit']{background-color:#ff2e64;color:#fff}</style>");

	WiFiManagerParameter custom_header("<h3>Temp2IoT Settings</h3>");

	//definitinos of custom parameters
	//prepare
	char char_sensorCnt[2];
	itoa(sensorCnt, char_sensorCnt, 10);

	char char_toggleSensors[6];
	if (toggleSensors)
		strncpy(char_toggleSensors, "true", 6);
	else
		strncpy(char_toggleSensors, "false", 6);

	//define
	WiFiManagerParameter custom_systemName("systemName", "Systemname", systemName, 20);
	WiFiManagerParameter custom_temp1Name("temp1Name", "Bezeichnung Sensor 1", temp1Name, 20);
	WiFiManagerParameter custom_temp2Name("temp2Name", "Bezeichnung Sensor 2", temp2Name, 20);

	//add parameters to wifiManager
	wifiManager.addParameter(&custom_header);
	wifiManager.addParameter(&custom_systemName);
	wifiManager.addParameter(&custom_temp1Name);
	wifiManager.addParameter(&custom_temp2Name);

	delay(500);

	//ToDo: Check cust. ntp server address
	//configTime(0, 0, "pool.ntp.org", "time.nist.gov");
	configTime(0, 0, ntpServer, "pool.ntp.org", "time.nist.gov");
	setenv("TZ", "CET-1CEST,M3.5.0,M10.5.0/3", 0);  // https://github.com/nayarsystems/posix_tz_db 

	//set config save notify callback
	wifiManager.setSaveConfigCallback(saveConfigCallback);

	wifiManager.autoConnect("Temp2IoT");


	server.on("/", handleRoot);
	server.on("/favicon.svg", handleFaviconSvg);
	server.on("/format", getFormat);
	server.on("/update", getUpdate);
	server.on("/reset", getReset);
	server.on("/config", getConfig);
	server.on("/setup", handleConfig);
	server.on("/api", handleApi);

	server.begin();

	//USE_SERIAL.print("IP address: ");
	//USE_SERIAL.println(WiFi.localIP());

	//read updated parameters
	strcpy(systemName, custom_systemName.getValue());
	strcpy(temp1Name, custom_temp1Name.getValue());
	strcpy(temp2Name, custom_temp2Name.getValue());

	//save the custom parameters to FS
	if (shouldSaveConfig)
		saveConfig();

	DS18B20.begin();
	SecureCounter = 0;

	USE_SERIAL.println();
	USE_SERIAL.println("HTTP Temp2IoT server started, you can reach the web UI on:");
	USE_SERIAL.print("http://");
	USE_SERIAL.print(WiFi.localIP());
	USE_SERIAL.println("/");
	digitalWrite(LED_BUILTIN, HIGH);  //turn the LED off
}

void saveConfig()
{
	DynamicJsonDocument json(1024);

	json["systemName"] = systemName;
	json["temp1Name"] = temp1Name;
	json["temp2Name"] = temp2Name;
	json["sensorCnt"] = sensorCnt;
	json["toggleSensors"] = toggleSensors;
	json["primaryColor"] = primaryColor;
	json["ntpServer"] = ntpServer;

	json["offsetValue1"] = offsetValue1;
	json["gainValue1"] = gainValue1;
	json["squareValue1"] = squareValue1;
	json["offsetValue2"] = offsetValue2;
	json["gainValue2"] = gainValue2;
	json["squareValue2"] = squareValue2;

	File configFile = SPIFFS.open("/config.json", "w");

	if (!configFile)
		USE_SERIAL.println("failed to open config file for writing");

	serializeJson(json, Serial);
	serializeJson(json, configFile);
}

void infoReset()
{
	USE_SERIAL.println("Format System");

	//reset Wifi-Setting
	WiFiManager wifiManager;
	wifiManager.resetSettings();

	//format Flash
	SPIFFS.format();

	//restart
	ESP.reset();
}

void restartX()
{
	ESP.reset();
}


void update_started()
{
	USE_SERIAL.println("CALLBACK:  HTTP update process started");
}

void update_finished()
{
	USE_SERIAL.println("CALLBACK:  HTTP update process finished");
}

void update_progress(int cur, int total)
{
	char progressString[10];
	float percent = ((float)cur / (float)total) * 100;
	sprintf(progressString, " %s",  String(percent).c_str());

	USE_SERIAL.printf("CALLBACK:  HTTP update process at %d of %d bytes...\n", cur, total);
}

void update_error(int err)
{
	char errorString[8];
	sprintf(errorString, "Err %d", err);

	USE_SERIAL.printf("CALLBACK:  HTTP update fatal error code %d\n", err);
}

void updateFirmware()
{
	USE_SERIAL.println("UPDATE:  Start update process...");
	ESPhttpUpdate.setLedPin(LED_BUILTIN, LOW);

	/*USE_SERIAL.println("UPDATE:  Stop ESP8266WebServer");
	server.close();
	server.stop();
	USE_SERIAL.println("UPDATE:  ESP8266WebServer is stopped");

	delay(500);*/


	USE_SERIAL.println("UPDATE:  Register callback events");
	// Add optional callback notifiers
	ESPhttpUpdate.onStart(update_started);
	ESPhttpUpdate.onEnd(update_finished);
	ESPhttpUpdate.onProgress(update_progress);
	ESPhttpUpdate.onError(update_error);


	USE_SERIAL.println("UPDATE:  Call update()");
	t_httpUpdate_return ret = ESPhttpUpdate.update(client, "https://pool.100prznt.de/temp2iot/bin/release/latest/Temp2IoT.ino.d1_mini.bin");


	switch (ret)
	{
		case HTTP_UPDATE_FAILED:
			USE_SERIAL.printf("HTTP_UPDATE_FAILD Error (%d): %s\n", ESPhttpUpdate.getLastError(), ESPhttpUpdate.getLastErrorString().c_str());
			break;
		case HTTP_UPDATE_NO_UPDATES:
			USE_SERIAL.println("HTTP_UPDATE_NO_UPDATES");
			break;
		case HTTP_UPDATE_OK:
			USE_SERIAL.println("HTTP_UPDATE_OK");
			break;
	}
}
 
void loop()
{
	server.handleClient();

	unsigned long currentMillis = millis();

	if (currentMillis % 5000 == 0) //each 5 seconds
	{ 
		readTemperature();
	}
}

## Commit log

2020-06-17 initial commit (src) :rocket:
    [temp2iot.fzz]
2020-06-18 add new photos
    [Temp2IoT_Enclosure.stl, Temp2IoT_EnclosureLogoCover.stl]
2020-06-19 update temperature per js
2020-10-23 add docu images
    [Temp2IoT_CaseLogoCover.stl, Temp2IoT_WeMosD1Mount.stl]
2021-06-24 Update V2
    [temp2iot.fzz]
2021-07-08 Final work of trend branch
    * add config for NTP server
    * add 1 and 24h measvalue queue
    * add mean values for api call
    * bugfix scheme# starage
    * debug output current version
    [Temp2IoT.ino]
2021-07-08 Add hiden setup page link
    * style up setup page
    * display current version on setup page
2021-07-14 error checking for temp readings
    [Temp2IoT.ino]
2022-01-28 Move to PrusaPrinters.org
    [Temp2IoT_CaseLogoCover.stl]
2022-07-04 Bugfix: toggle sensors in js
    [Temp2IoT.ino]
2022-08-08 fix width for value str
    [Temp2IoT.ino]
2023-01-10 Add power supply link
2023-07-10 Fix GPIO assignments
    Bugfix for 1-wire connection errors
    [Temp2IoT.ino]
